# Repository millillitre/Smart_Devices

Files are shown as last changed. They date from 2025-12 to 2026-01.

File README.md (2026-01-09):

# Smart Devices

Développé par Marie-Lien Da Costa Bento, Célian Hilal Hamdan et Jean-Phillipe Loubejac--Combalbert pour le cours *Microcontroller and Open Source Hardware*.

## Organisation

Dans ce repo, vous pourrez trouver:

- sur la branche *main*:
  - Les fichiers de schémas et de routage [KiCad](/KiCAD/)
  - Les fichiers de simulation [LTSpice](/LTSpice/)
  - Le montage du [transceiver LoRa](/LoRa) pour notre réseau et sa [configuration arduino](/LoRa/LoRaConnection.ino).
  - Les configurations [MIT_App](/MIT_App/) sur la partie application.
  - Les fichiers de configuration [Node-RED](/NodeRED/)
  - Les différents [documents](/docs/) (photos, screenshots) utilisés pour appuyer notre propos.
  - La licence *Creative Commons*
  - La [datasheet](/Datasheet_gaz_sensor.pdf) de notre capteur.
  - [README.md](/README.md)

## Usage

### Matériels

Pour effectuer le projet, nous avons utilisé:
    - une carte Arduino UNO, 
    - un module LoRa,
    - les capteurs de gaz conçues à l'AIME.

### Communication

Pour obtenir les données via LoRa, nous avons eu besoin d'un accès à une gateway LoRa and un serveur (Chirpstack de l'INSA Toulouse dans notre cas)

## Le capteur de GAZ effectué à l'AIME

Voici, étape par étape, le travail que nous avons effectué pour fabriquer notre capteur à l'AIME.

### Etape 1 : Fabrication des nanoparticules du capteur

1. Synthèse des nanoparticules : préparation de nanobâtonnets de WO₃

   - Préparation des précurseurs (Na₂WO₄·2H₂O et NaCl)
   - Préparation de l’acide (HCl)
   - Recuit et refroidissement

2. Traitement post-synthèse des nanoparticules

   - Centrifugation
   - Stockage des nanobâtonnets dans un flacon

### Etape 2: Fabrication de la puce du capteur

1. Procédé de fabrication de la puce : [photolithographie métallique](/docs/Mask.jpg)

   - Séchage et dépôt de résine photosensible
   - Exposition aux UV
   - Développement
   - Gravure de l’aluminium
   - Recuit du métal
   - Sélection des meilleures puces

2. Conditionnement et assemblage du dispositif

   - Découpe diamantée de la puce
   - Montage sur le support à l’aide d’un adhésif époxy et polymérisation
   - Soudage par ultrasons des fils aluminium-silicium pour les connexions électriques

### Etape 3 : Fabrication de la phase finale du capteur

1. Procédé de diélectrophorèse

   - Intégration des nanoparticules (NP) par diélectrophorèse
   - Application d’une tension sinusoïdale aux électrodes interdigitées Peigne d'électrodes
   - Positionnement précis des nanoparticules sur le dispositif

### Etape 4 : Tests du capteur

1. Tests électriques préliminaires

   - Mesure des résistances aux bornes du capteur
   - Vérification des connexions électriques et du fonctionnement

2. Tests fonctionnels sous atmosphère gazeuse

   - Tests sous méthane, air synthétique et éthanol à 250 °C (522 K)

### Etape 5 : Caractérisation du capteur

1. Analyse par microscopie électronique à balayage (MEB)

   - Observation du capteur et de ses nanobâtonnets par [MEB](/docs/MEB.tif)

## Amplification du signal

Lors des TP d'Analog Electronic Labs, on a modélisé sur LTSpice un amplificateur. On peut le tretrouver [ici](/LTSpice/ampliyoplait_avec_capteur.asc).

Nous avons également mis en place l'amplificateur en banc de test [ici](/docs/montage_ampliop.png).

## Programmation du capteur et transmission via LoRa

### Montage et soudure du banc de test

Nous avons soudé et monté un transceiver LoRa pour notre réseau. Les détails de ces étapes sont accessibles [ici](/LoRa/README.md).

Nous avons également testé électriquement avec un wattmètre notre soudure.

### Transmission LoRa

Les communications sont accessibles sur [https://srv-chirpstack.insa-toulouse.fr](chirpstack).

## Conception du PCB via KiCAD
Nous avons suivi les instructions de M.Biganzoli, et nous avons décidé de faire une seule face, pour ne pas avoir de via et éviter d'avoir à connecter par nous me^me l'autre côté à l'aide de fils. 

Les fichiers du PCB sont trouvables [ici](/KiCAD/kicad-roger-shield-uno/).

<p align="center">
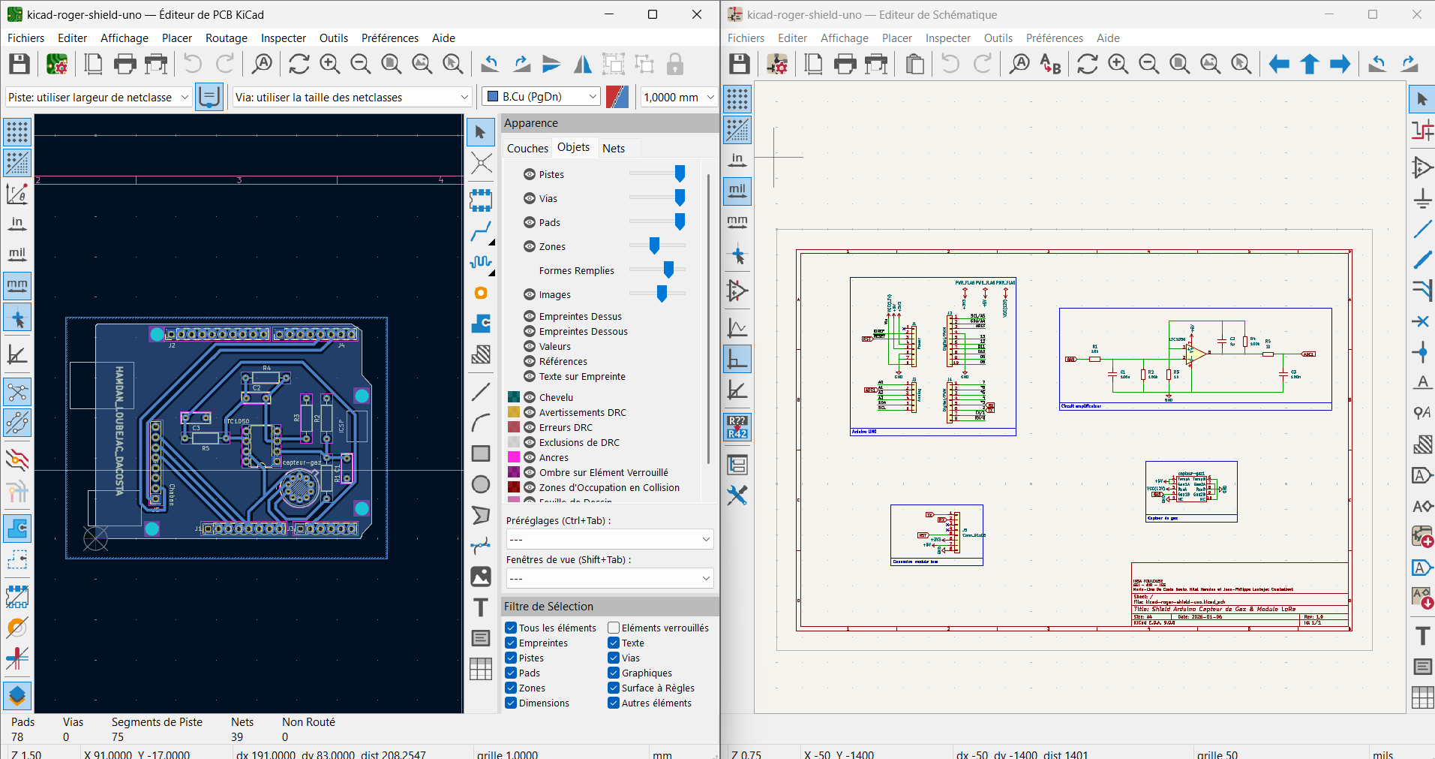
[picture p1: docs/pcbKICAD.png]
Design du PCB
  
</p>

Nous avons pu ensuite l'imprimer avec Cathy et nous avons percé un à un les trous. Nous avons également souder par la suite. Ci-dessous notre PCB imprimé et le montage:

<p align="center">
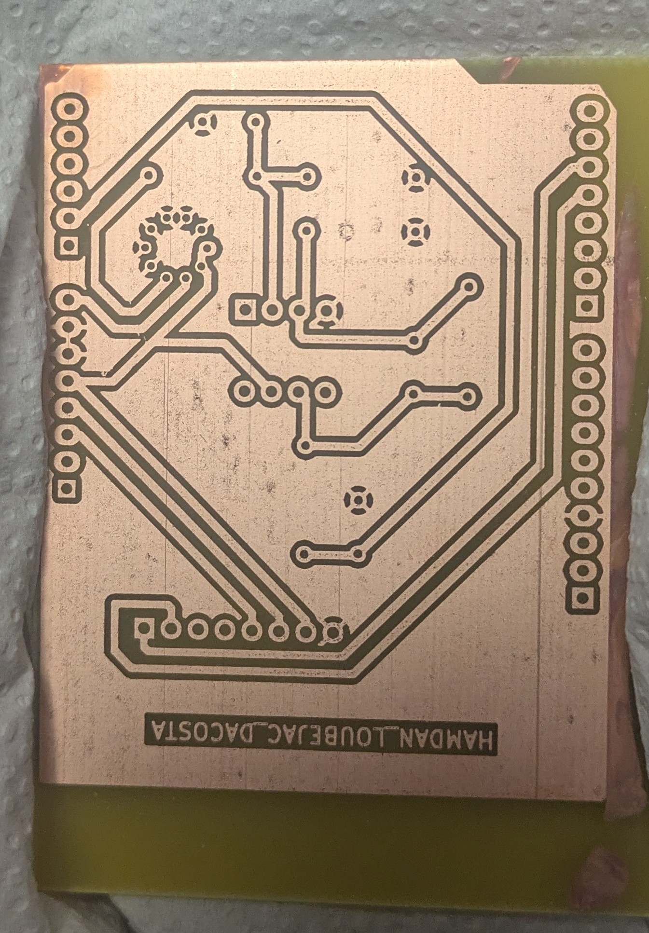
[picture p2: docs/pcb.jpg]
  
</p>

<p align="center">
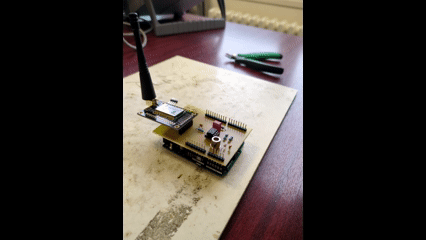
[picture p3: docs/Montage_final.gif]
  
</p>

## Node-RED

Nous avons développé un tableau de bord avec [Node-RED](/NodeRED/flows.json) pour visualiser les données transmises via LoRa. Ce tableau de bord simple affiche :
    - la dernière valeur mesurée,
    - une jauge indiquant la position de cette valeur par rapport aux seuils minimum et maximum de gaz détectables par le capteur,
    - ainsi que la variation de la quantité de gaz.

<p align="center">
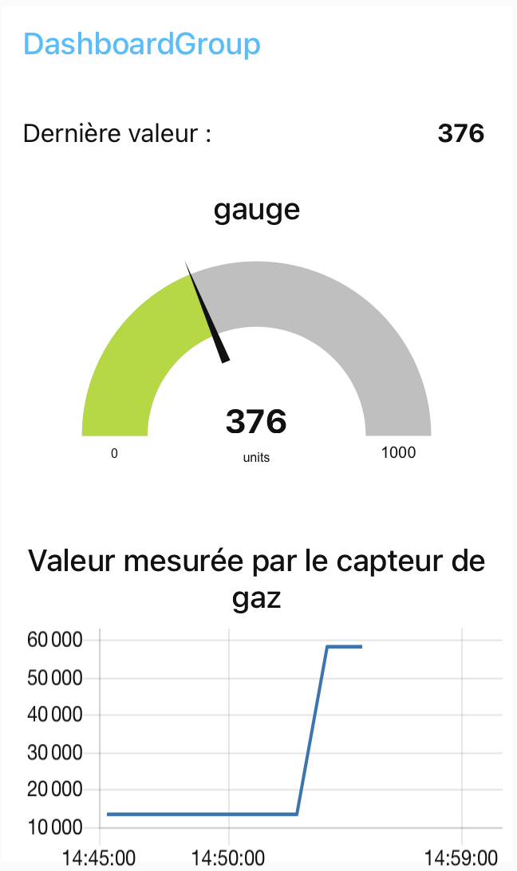
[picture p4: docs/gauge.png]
Jauge de mesure
  
</p>

Ensuite nous avons continué notre développement ([flows2.json](/NodeRED/flows2.json)) en ajoutant une partie pour créer un fichier json pour envoyer en http la valeur du capteur pour permettre à celle-ci d'être récupérée par l'application mentionnée dans la partie suivante.

## MIT Application
Nous avons mis en place une application pour mobile via MIT App, elle se trouve [ici](/MIT_App/Application/). L'idée de cette application est d'afficher la valeur du capteur de gaz en temps réel, qui change de coucleur si la valeur est critique et qui affiche un graphe d'évolution des valeurs.

- Valeur sous le seuil critique :
<p align="center">
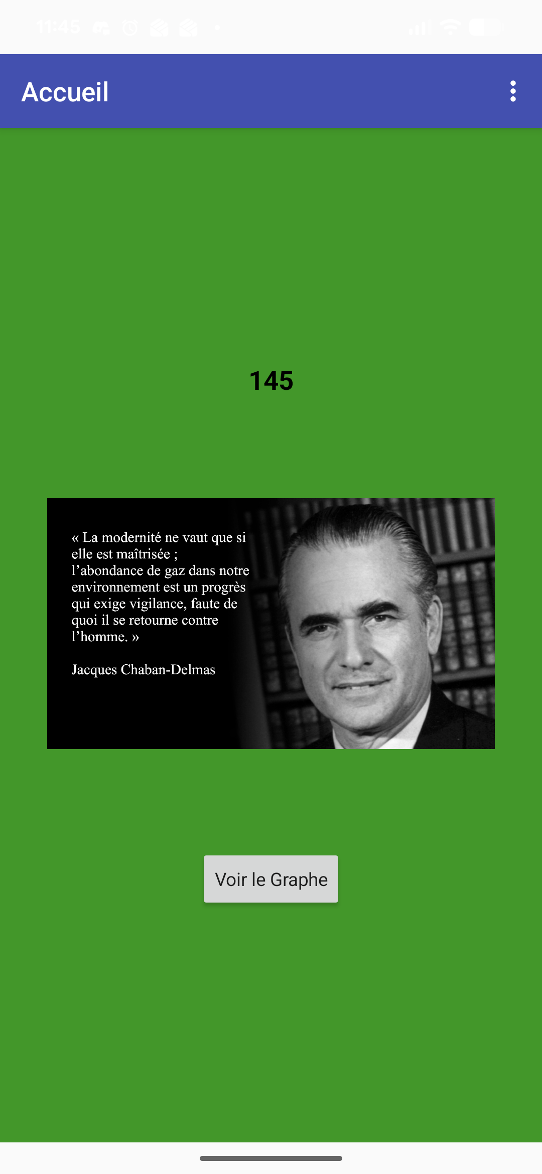
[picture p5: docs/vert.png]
Vert
  
</p>

- Valeur au dessus du seuil critique :
<p align="center">
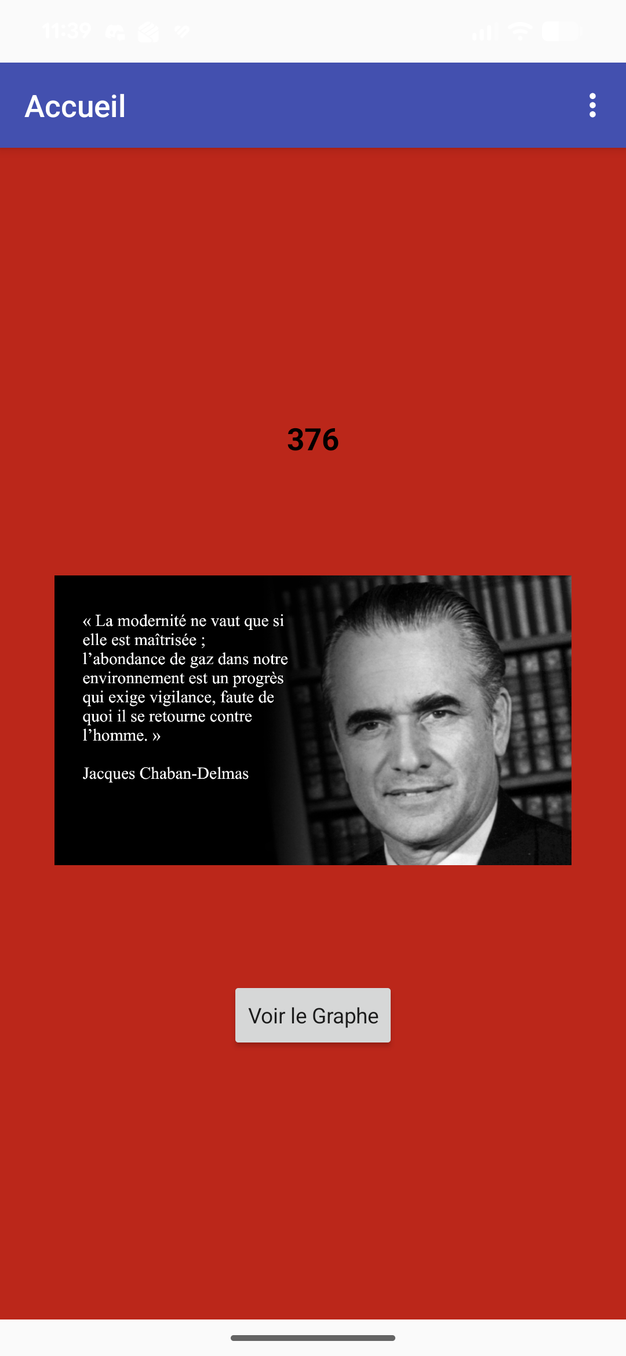
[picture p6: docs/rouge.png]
Rouge
  
</p>

- Visualisation graphique :
<p align="center">
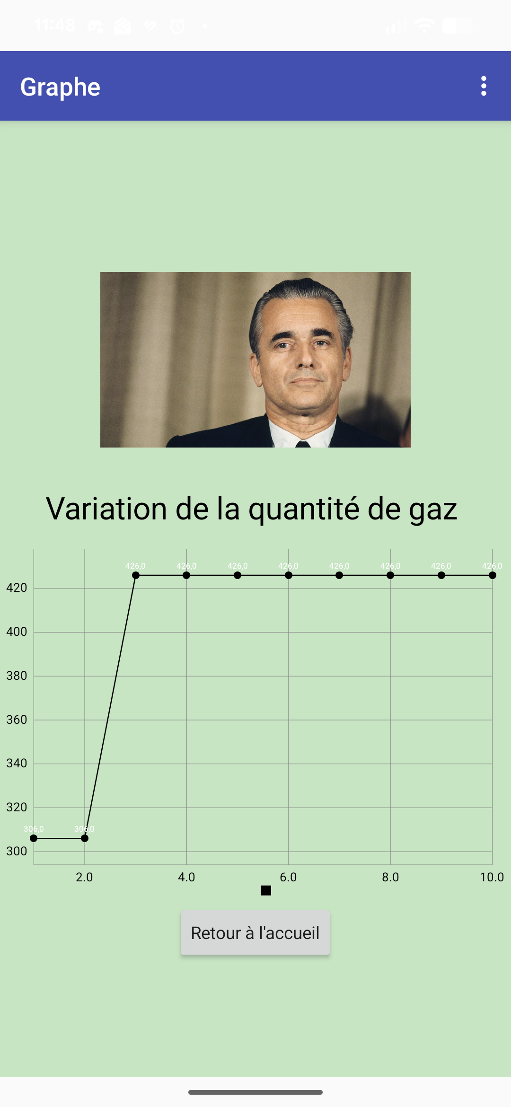
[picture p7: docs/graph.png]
Graphe
  
</p>

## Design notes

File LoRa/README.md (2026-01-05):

# Construction du transceiver LoRa 

## Soudure

On a un module LoRa [RN2483](/docs/RN2483_datasheet.pdf) dont on va souder seulement les pins qui nous intéresse sur une carte fille:

- `GND` : la terre
- `Vin` : tension d'alimentation dont on aura besoin pour alimenter notre capteur
- `3v3`
- `RST` : reset
- Les 4 bus de communication UART:
  - `RTS`
  - `CTS`
  - `RX`
  - `TX`

## Programmes

- [Initialisation](/LoRaConnection)
- [Ajout d'une LED](/LoRaConnectionWithLED)

## Quelques photos

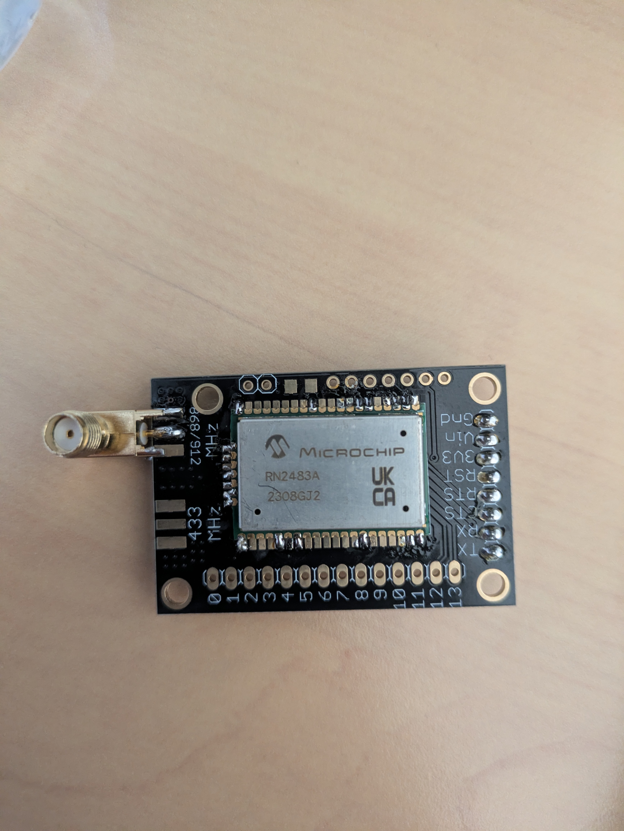
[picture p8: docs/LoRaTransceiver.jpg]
Le transceiver LoRa
- 
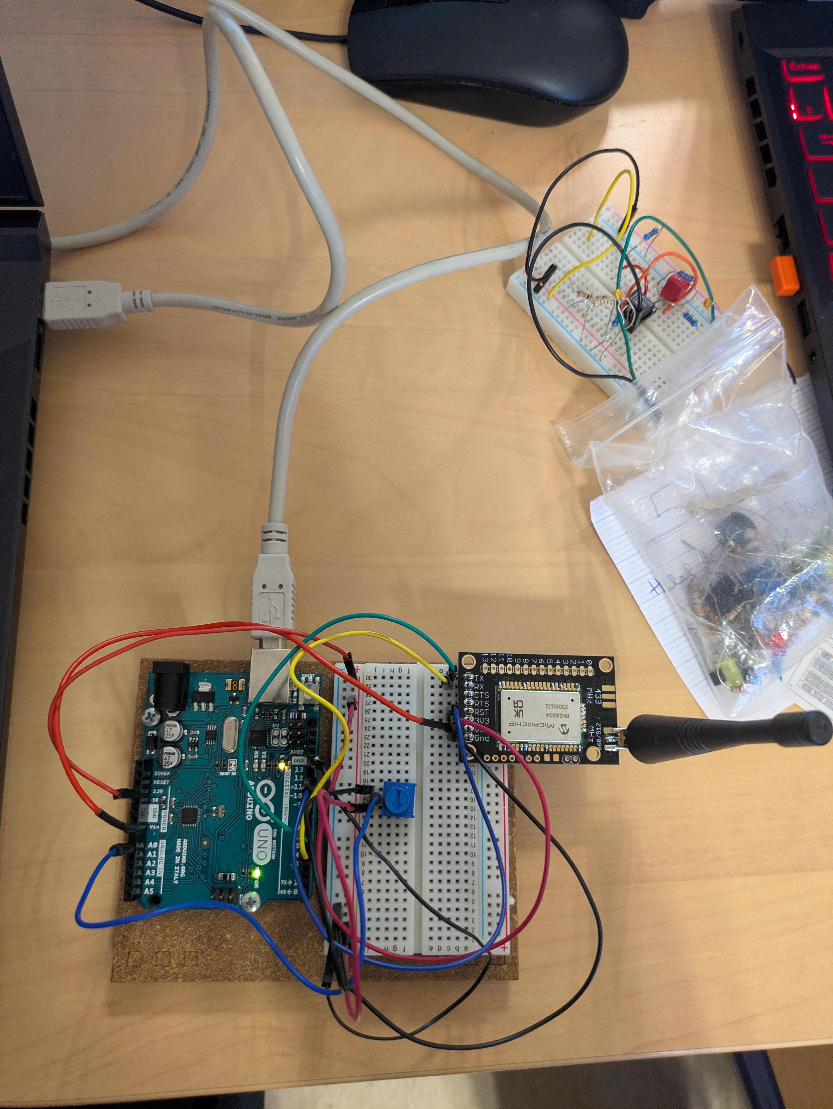
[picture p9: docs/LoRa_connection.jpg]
La connexion du transceiver à une carte Arduino
-  avec un potentiomètre.
- La LED qui s'allume selon la valeur du potentiomètre.
- Les données reçues sur Chirpstack

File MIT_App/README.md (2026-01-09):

# MIT App

## Description

L'idée est de pouvoir utiliser une application directement sur notre smartphone pour obtenir les données de notre capteur de gaz.

### [TP test](/MIT_App/TP_test/)

Dans cette partie, nous essayons de faire fonctionner un TP sur une application MIT connecté à une carte arduino.

Dans la capture des [Blocks](/MIT_App/TP_test/Block.png), nous avons les blocks que nous avons utilisés, et dans la capture du [Screen](/MIT_App/TP_test/Screen.png) on peut voir la User Interface.

Le fichier [.aia](/MIT_App/TP_test/TP5_MOSH.aia) contient notre application.

### [Gaz Version](/MIT_App/Application/)

Dans cette partie, nous mettons en place l'application pour notre montage avec le gaz sensor. Dans les capture des [Block 1](/MIT_App/Application/block_screen1.png) et [Block 2](/MIT_App/Application/block_screen2.png), nous avons les blocks que nous avons utilisés,

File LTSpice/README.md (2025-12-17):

# LTSpice

Ici, vous trouverez les fichiers LTSpice pour notre projet:
  - [Le capteur de gaz](/LTSpice/le_gros_capteur.asc) et [ses connections](/LTSpice/le_gros_capteur.asy)
  - [Le montage de l'amplificateur avec le capteur de gaz](/LTSpice/ampliyoplait_avec_capteur.asc)

## Amplificateur

Voici une photo de l'amplificateur:
Ampli

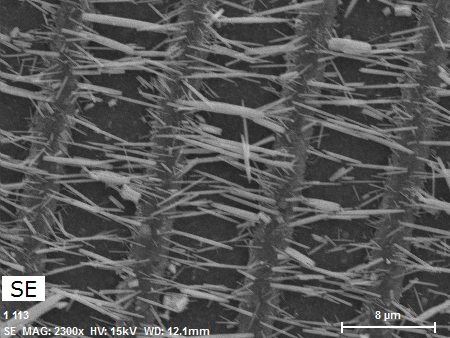
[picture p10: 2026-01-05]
docs/MEB.tif

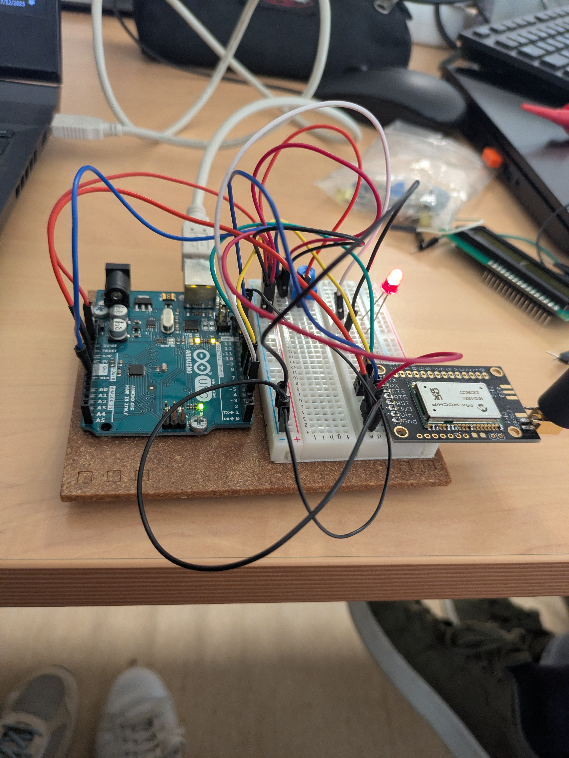
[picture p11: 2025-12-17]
docs/LoRa_LED.jpg

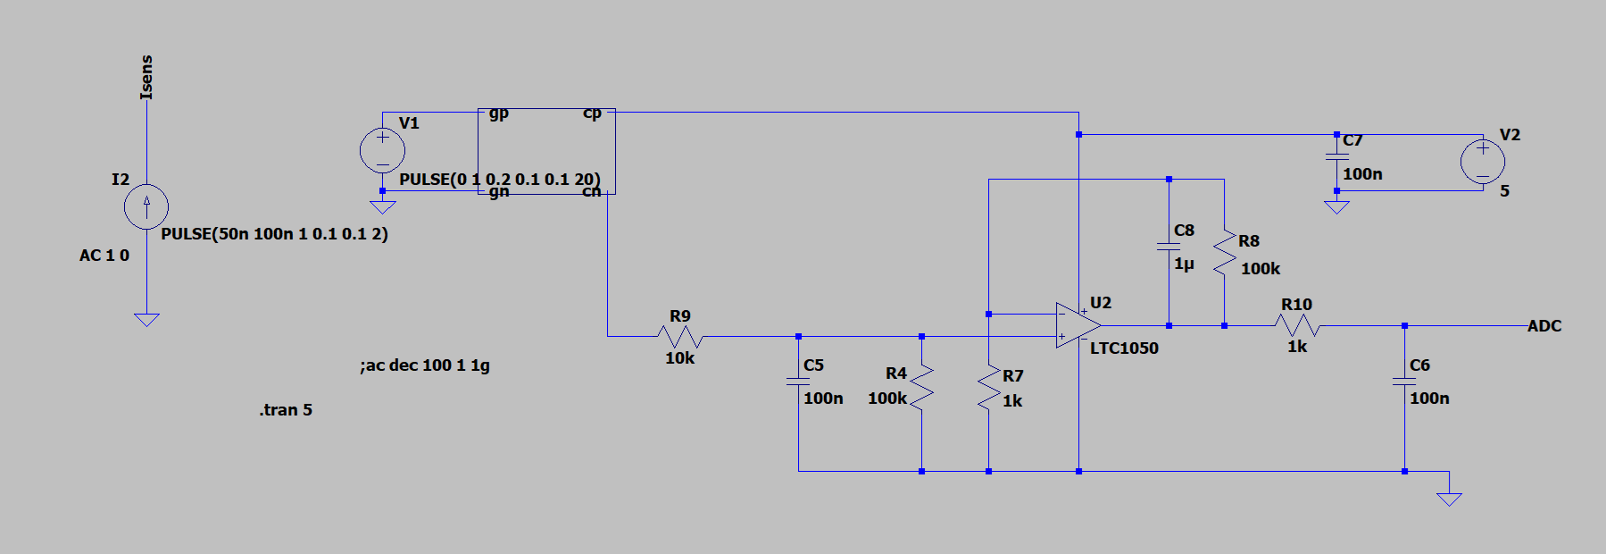
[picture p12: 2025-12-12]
docs/ampliyoplait.png

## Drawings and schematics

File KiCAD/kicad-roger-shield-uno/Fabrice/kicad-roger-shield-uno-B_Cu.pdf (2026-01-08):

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

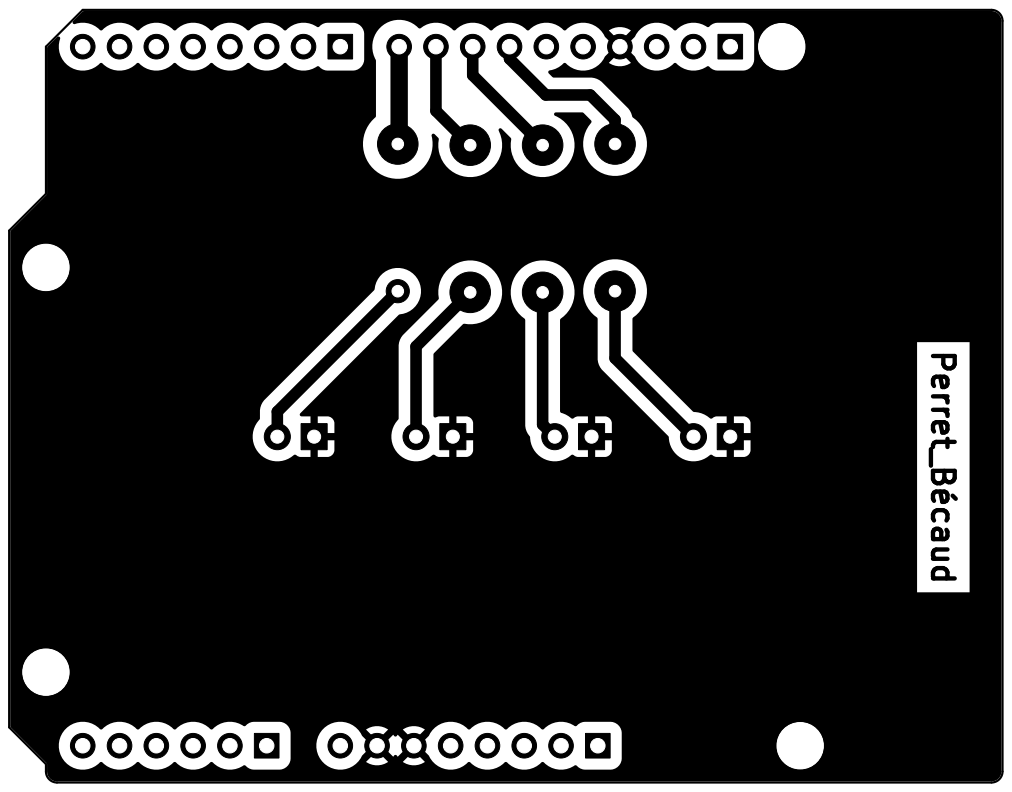
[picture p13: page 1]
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

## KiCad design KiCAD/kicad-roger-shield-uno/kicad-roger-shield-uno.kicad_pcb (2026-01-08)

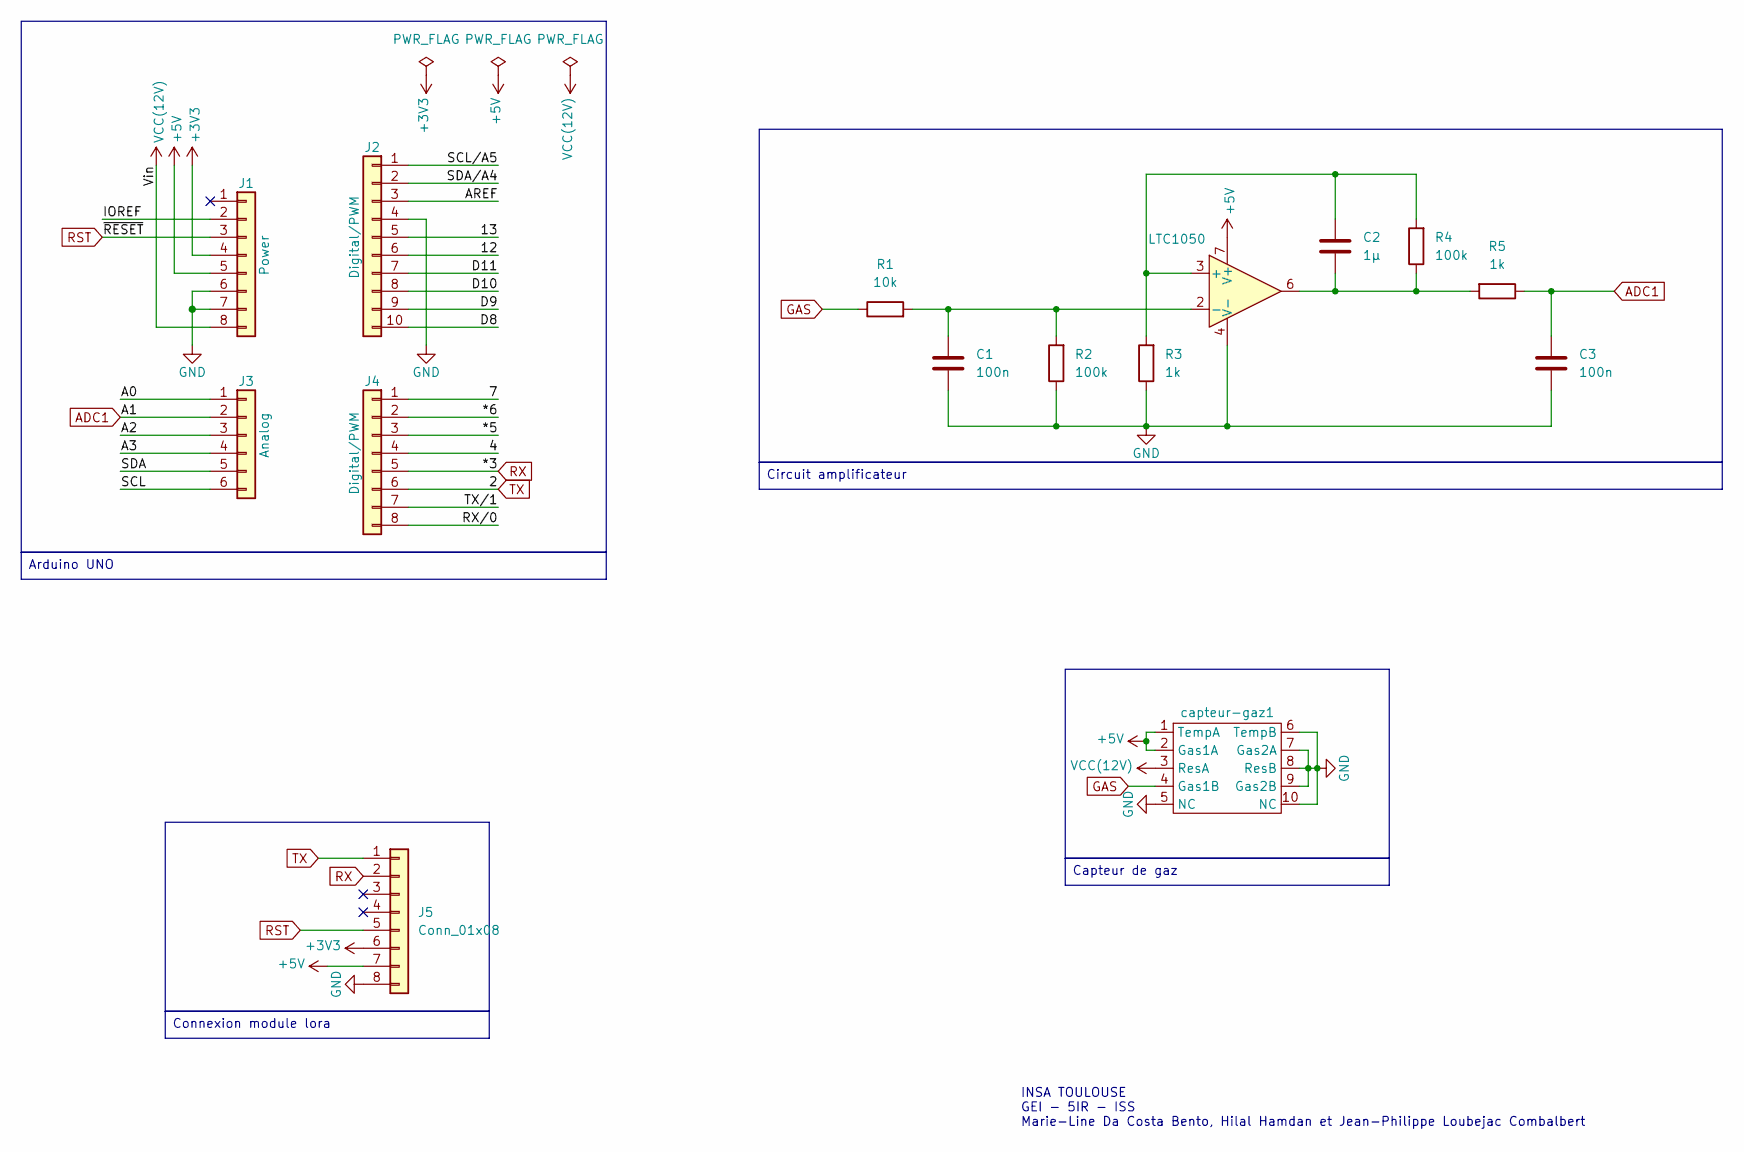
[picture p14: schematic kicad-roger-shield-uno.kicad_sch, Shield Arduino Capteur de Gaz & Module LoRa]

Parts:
C1, C3: 100n; C_Disc_D7.0mm_W2.5mm_P5.00mm
C2: 1µ; C_Disc_D7.0mm_W2.5mm_P5.00mm
J1: Power; PinHeader_1x08_P2.54mm_Vertical
J2: Digital/PWM; PinHeader_1x10_P2.54mm_Vertical
J3: Analog; PinHeader_1x06_P2.54mm_Vertical
J4: Digital/PWM; PinHeader_1x08_P2.54mm_Vertical
J5: Conn_01x08; PinSocket_1x08_P2.54mm_Vertical
R1: 10k; R_Axial_DIN0207_L6.3mm_D2.5mm_P10.16mm_Horizontal
R2, R4: 100k; R_Axial_DIN0207_L6.3mm_D2.5mm_P10.16mm_Horizontal
R3, R5: 1k; R_Axial_DIN0207_L6.3mm_D2.5mm_P10.16mm_Horizontal
U2: LTC1050; DIP-8_W7.62mm
capteur-gaz1: TO-5-10_Window

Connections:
+3V3: J1.4, J5.6
+5V: J1.5, J5.7, U2.7 (V+), capteur-gaz1.1 (TempA), capteur-gaz1.2 (Gas1A); also elsewhere on the board
/4: J4.4
/7: J4.1
/12: J2.6
/13: J2.5
/*5: J4.3
/*6: J4.2
/A0: J3.1
/A2: J3.3
/A3: J3.4
/AREF: J2.3
/D8: J2.10
/D9: J2.9
/D10: J2.8
/D11: J2.7
/IOREF: J1.2
/RX/0: J4.8
/SCL: J3.6
/SCL/A5: J2.1
/SDA: J3.5
/SDA/A4: J2.2
/TX/1: J4.7
ADC1: C3.1, J3.2, R5.1
GAS: R1.1, capteur-gaz1.4 (Gas1B); also elsewhere on the board
GND: C1.2, C3.2, J1.6, J1.7, J2.4, J5.8, R2.1, R3.1, U2.4 (V-), capteur-gaz1.5 (NC), capteur-gaz1.6 (TempB), capteur-gaz1.7 (Gas2A), capteur-gaz1.8 (ResB), capteur-gaz1.9 (Gas2B), capteur-gaz1.10 (NC); also elsewhere on the board
unnamed: C2.2, R4.1, R5.2, U2.6
unnamed: C2.1, R3.2, R4.2, U2.3 (+)
unnamed: C1.1, R1.2, R2.2, U2.2 (-)
RST: J1.3, J5.5
RX: J4.5, J5.2
TX: J4.6, J5.1
VCC(12V): J1.8, capteur-gaz1.3 (ResA); also elsewhere on the board

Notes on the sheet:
INSA TOULOUSE GEI - 5IR - ISS Marie-Line Da Costa Bento, Hilal Hamdan et Jean-Philippe Loubejac Combalbert
Circuit amplificateur
Arduino UNO
Capteur de gaz
Connexion module lora

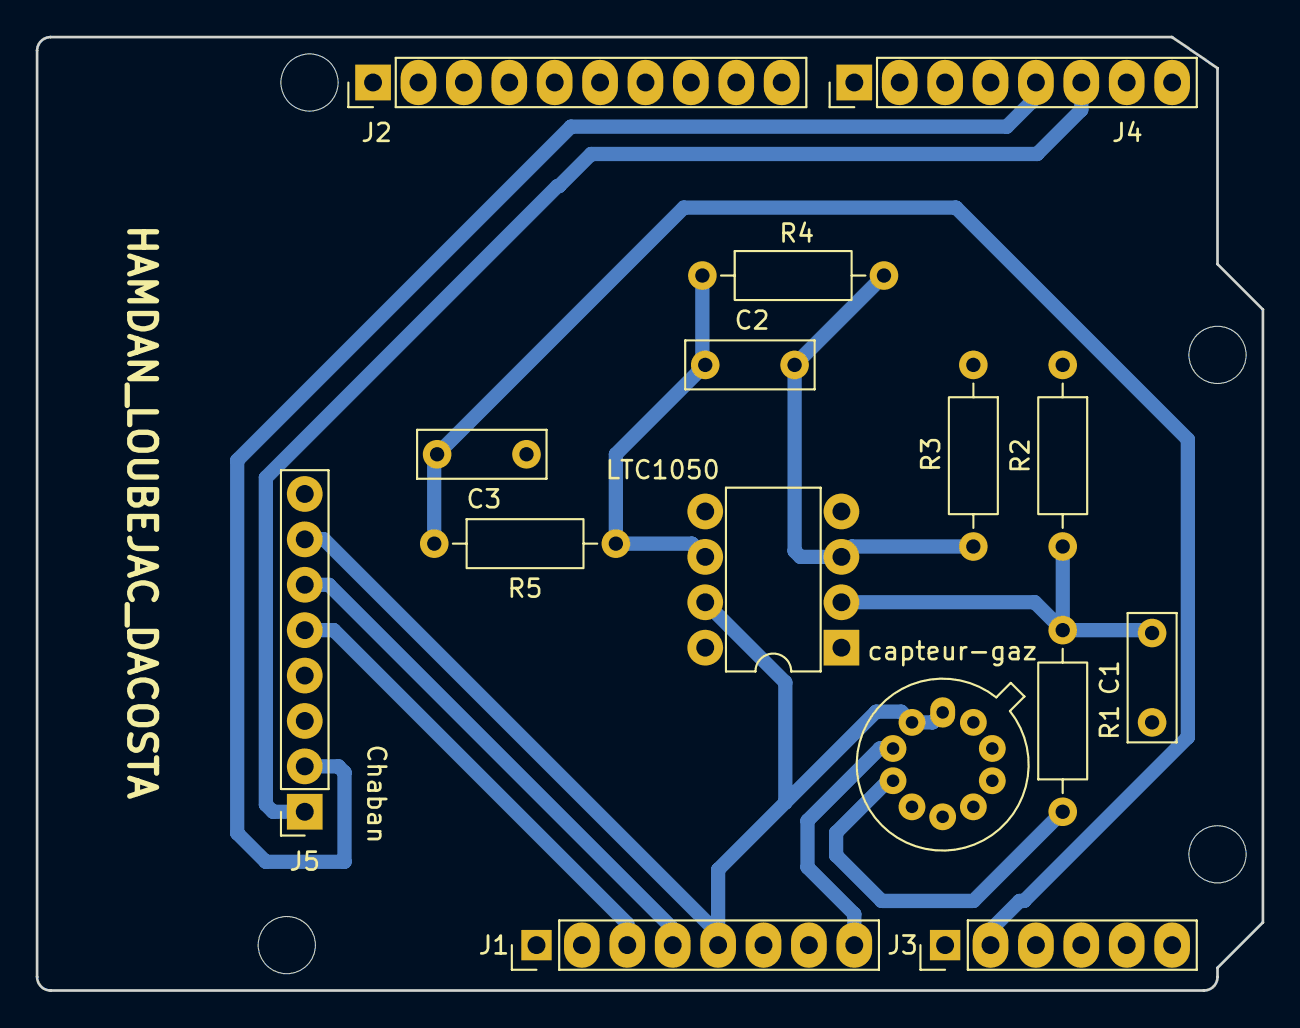
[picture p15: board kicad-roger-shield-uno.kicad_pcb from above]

Board: 2 copper layers, 68.6 x 53.3 mm, 19 parts (0 on the bottom side), 12 nets.

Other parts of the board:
MH1, MH2, MH3, MH4: MountingHole_3.2mm
capteur-gaz: TO-5-10_Window

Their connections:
+5V: capteur-gaz.1 (TempA), capteur-gaz.2 (Gas1A); also elsewhere on the board
GAS: capteur-gaz.4 (Gas1B); also elsewhere on the board
GND: capteur-gaz.5 (NC), capteur-gaz.6 (TempB), capteur-gaz.7 (Gas2A), capteur-gaz.8 (ResB), capteur-gaz.9 (Gas2B), capteur-gaz.10 (NC); also elsewhere on the board
VCC(12V): capteur-gaz.3 (ResA); also elsewhere on the board

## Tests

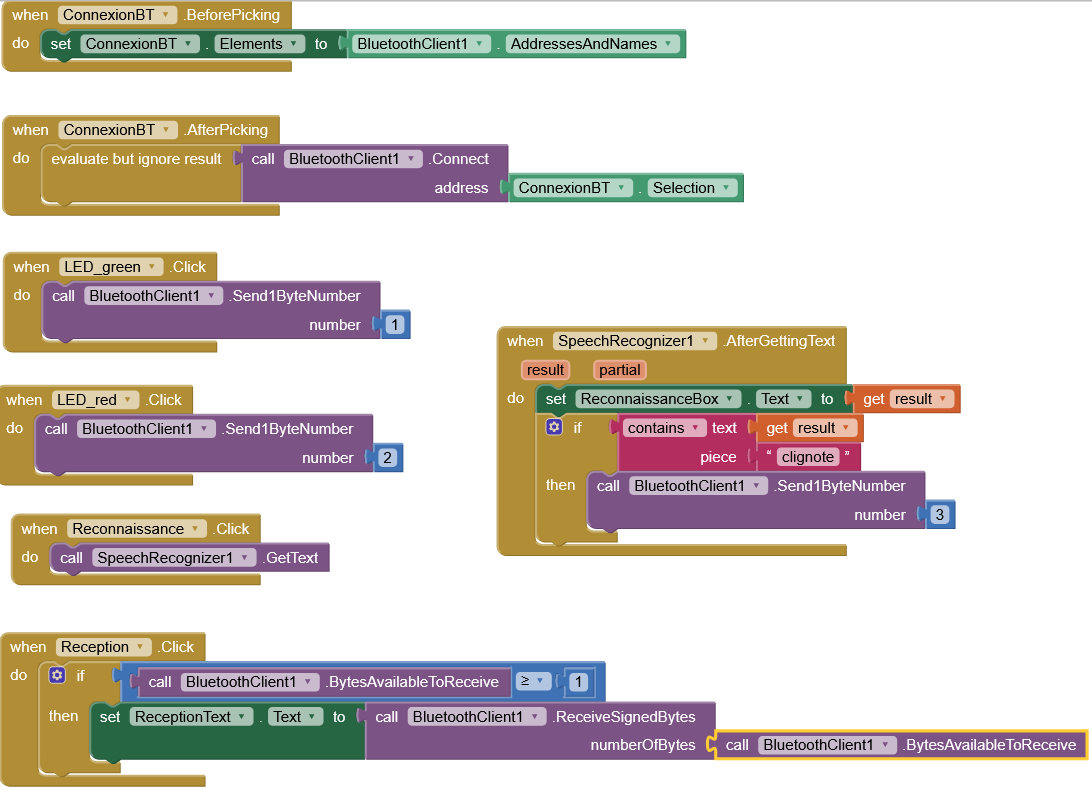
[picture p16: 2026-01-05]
MIT_App/TP_test/Block.png

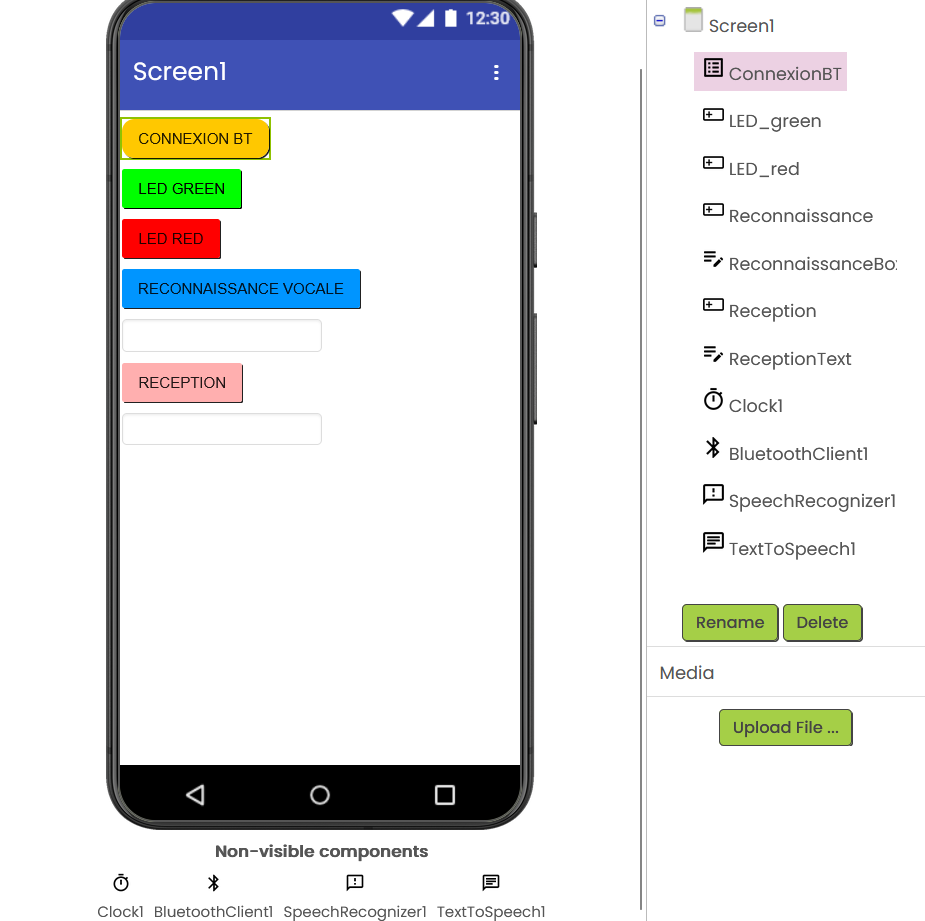
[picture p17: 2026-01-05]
MIT_App/TP_test/Screen.png

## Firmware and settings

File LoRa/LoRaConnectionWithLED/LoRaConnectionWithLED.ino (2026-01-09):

#include <SoftwareSerial.h>
#include <rn2xx3.h> //https://github.com/jpmeijers/RN2483-Arduino-Library/blob/master/src/rn2xx3.h


#define txPin 5
#define rxPin 6
#define LedPin 2

SoftwareSerial mySerial(rxPin, txPin);
rn2xx3 Lora(mySerial);

void commLoRa(String msg)
{
    Lora.tx(msg);
}

void initialize_radio()
{
    // Reset RN2483
    pinMode(12, OUTPUT);
    digitalWrite(12, LOW);
    delay(500);
    digitalWrite(12, HIGH);

    delay(100); // wait for the RN2xx3's startup message
    mySerial.flush();

    Lora.autobaud();

    String hweui = Lora.hweui();
    while (hweui.length() != 16)
    {
        Serial.println("Communication with RN2483 unsuccessful. Power cycle the board.");
        Serial.println(hweui);
        delay(10000);
        hweui = Lora.hweui();
    }

    // print out the HWEUI
    Serial.println("When using OTAA, register this DevEUI: ");
    Serial.println(Lora.hweui());
    Serial.println("RN2483 firmware version:");
    Serial.println(Lora.sysver());

    // Join via OTAA
    Serial.println("Trying to join Chirpstack");
    bool join_result = false;
    const char *Eui = "059e6eb52f689162"; // Here put the AppEUI provided by Chirpstack
    const char *Key = "d56f6d7d3433ed17318e00ec3dd543d2"; // Here put the AppKey provided by Chirpstack
    join_result = Lora.initOTAA(Eui, Key);

    while (!join_result)
    {
        Serial.println("Unable to join. Trying again...");
        delay(10000);
        join_result = Lora.init();
    }
    Serial.println("Successfully joined Chirpstack!");
}

void setup()
{
    pinMode(LedPin, OUTPUT);
    Serial.begin(57600);  // serial port to computer
    mySerial.begin(9600); // serial port to radio
    Serial.println("Startup LoRa");
    initialize_radio();
}

void loop()
{
    // Exemple
    int sensorValue = analogRead(A0); //valeur dans la pin A0
    Serial.println(sensorValue);
    if (sensorValue > 500){
        digitalWrite(LedPin, HIGH);
    }
    else{
        digitalWrite(LedPin, LOW);
    }
    // Envoyer via LoRa
    commLoRa(String(sensorValue));
    delay(10000); // Attendre 10 secondes avant le prochain envoi
}

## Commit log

2025-12-08 Fix formatting of UART communication bus list
2025-12-12 add: ltspice circuit
2025-12-12 add: une superbe image du circuit
2025-12-17 Add LoRa connection image and update documentation
    - Added a new image showing the LoRa transceiver connection to Arduino in docs/LoRa_connection.jpg.
2025-12-17 Add LoRa LED example and update documentation
2026-01-05 Add MIT App project files and documentation
    Added initial files for the MIT App project, including application source (.aia), block and screen images, and a README describing the app and its connection to Arduino.
2026-01-05 Add fabrication steps and images to documentation
    Expanded the README.md with detailed step-by-step instructions for sensor fabrication, including nanoparticle synthesis, chip manufacturing, assembly, testing, and characterization. Added references 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
2026-01-05 Enable LoRa data transmission and update documentation
    Uncommented the LoRa data transmission and delay in LoRaConnectionWithLED.ino to send sensor values every 10 seconds. Updated LoRa/README.md and main README.md with additional documentation and added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
2026-01-05 Remove Arduino code references and README
    Deleted the Arduino/README.md file and removed references to Arduino code from the main README.md.
2026-01-06 Add initial Node-RED flow configuration
2026-01-06 Add gas sensor datasheet and update README
    Added Datasheet_gaz_sensor.pdf to the repository.
2026-01-08 add: gitignore to ignore kicad backups file
2026-01-08 add: kicad roger project
    [kicad-roger-shield-uno.kicad_pcb, kicad-roger-shield-uno.kicad_sch]
2026-01-09 Update README with project results and PCB details
2026-01-09 Update PCB image in README and add pcb.jpg
2026-01-09 Uploading screen of KiCAD
2026-01-09 Update README with images for gas sensor application
    Added images for critical and non-critical gas sensor values.
2026-01-09 add screen flows 2
